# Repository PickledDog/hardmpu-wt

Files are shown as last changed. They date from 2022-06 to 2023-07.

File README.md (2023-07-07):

# hardmpu-wt
 HardMPU with wavetable module support

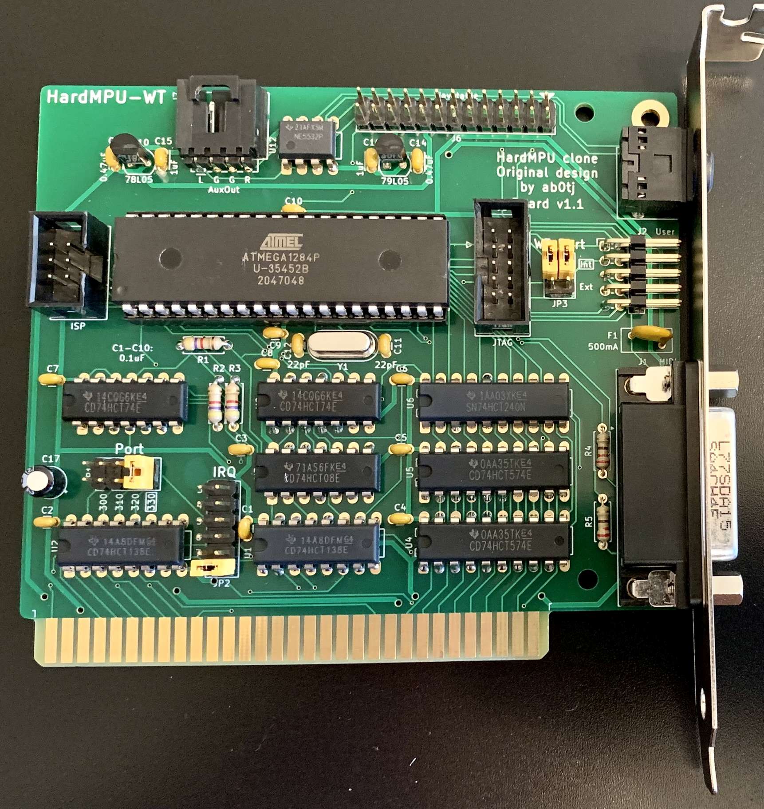
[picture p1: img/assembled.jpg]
Assembled HardMPU


## Overview
This is a clone of ab0tj's HardMPU board. I wanted one with a "Wave Blaster" header, so... here it is! If you don't need to install a wavetable module on your HardMPU, rather use ab0tj's original board. In particular, to quote the HardMPU repo, `the circuit design is free for non-commercial use.` The presence of this implementation does not permit commercial exploitation. If you build this, you may do so only for your own personal use. All [software](https://github.com/ab0tj/HardMPU/) is bound by the terms of the GPL. 

## Initial setup
The ATmega needs to be programmed before use. This can be done using any AVR programmer (AVRISP, STK500, USBtinyISP, USBasp etc), or a universal programmer (TL866, T48).

### Using an AVR programmer
This method programs the ATmega chip in-place (with the board fully assembled), through the J4 ISP connector. The listed programmers work similarly, but AVRDUDE will need to be told what programmer you are using. This example uses the [programmer from Pololu](https://www.pololu.com/product/3172).

Program the board loose (not plugged into a computer!) with the programmer configured to power the target at 5V. The required firmware can be found [in ab0tj's repository](https://github.com/ab0tj/HardMPU/tree/master/bin) (download all files), and [AVRDUDE](https://github.com/avrdudes/avrdude/) is used to install the firmware onto the ATmega.

You will need to modify the `program.bat` to reflect your programmer and environment. For example, to use a Pololu programmer detected at COM4, change (per-line):
```
-c usbasp-clone
```
to
```
-c stk500v2 -P COM4
```
For Mac and Linux, change the BATch file to a shell script and adapt it accordingly (use `/dev/ttyUSB0` instead of `COM4` etc).

### Using a TL866
If you're using a TL866 or T48, the firmware is programmed directly to the ATmega chip before installing it - the J4 connector isn't used here, and can be omitted. Download `HardMPU.hex` from [ab0tj's repository](https://github.com/ab0tj/HardMPU/tree/master/bin) and open it with the standard XGpro tool. Go to the **Config** tab and set the fuses as follows:

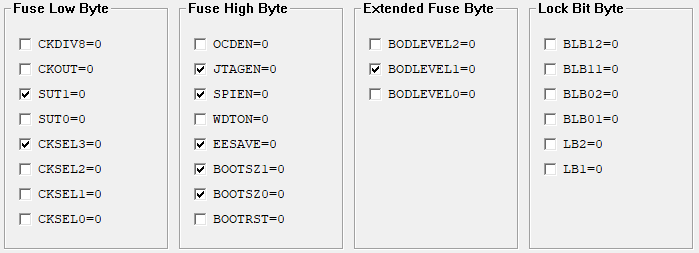
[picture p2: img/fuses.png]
ATmega1284 fuse config


With the firmware loaded and the fuses set, go ahead and program the ATmega chip.

## User port
The optional User port (J2) allows adventurous builders to add features to the board, either internally or externally. It breaks out 4 GPIO pins, an I²C interface, the "Internal" serial interface (shared with the Wavetable header), and fused power and ground pins. Either regular or right-angled header (as pictured) can be installed in the J2 position; a hole will need to be cut in the bracket for external access. You will need to write your own code to use these interfaces - maybe add a status display using a common I²C LCD? The possibilities are not particularly limited!

## Usage
With the card built and the chip programmed, it's ready to be installed in the ISA slot of your vintage PC. Copy `hardmpu.com` from the firmware folder above to the PC's hard drive - this is the config tool for HardMPU. Use it to select between internal and external MIDI devices, enable a delay for "rev 0" Roland MT-32s, and other miscellaneous options. Settings *do not persist* across reboots, so this will need to be added to `autoexec.bat` if the defaults aren't adequate.

### External MIDI
To connect it to an external synthesizer, you'll need a "Sound Blaster MIDI" cable - you can find a used one, [buy a new one](https://www.ebay.com/sch/i.html?_nkw=game+port+midi+cable), or [build your own](https://github.com/PickledDog/sb-midi). If shopping for a new one, *make sure to pick the one with large black DA-15 plugs* since it has the electronics in the plug. ***Do not use the "metal plugs" kind, they are passive and may damage your synthesizer.***

### Internal MIDI ("Wave Blaster")
Plug the wavetable board onto the 26-pin header, aligning the pin 1 arrows on both boards. Audio is output through both the 3.5mm jack and the AuxOut header on the board. The latter can be fed into your regular sound card using a standard "MPC2" CD Audio cable (assuming it has a spare input). You will need to use the `hardmpu.com` tool to select the internal MIDI port.

## Part selection
The design permits "nicer" parts than necessary - for example, the audio jack footprint accepts both switched and unswitched sockets. Not all pads and holes in the board need to be filled. The OPA2134 can be substituted for other common dual opamps (like the NE5532). Some connectors are optional - J2 and J5 in particular are seldom-used. An [ATmega1284](https://www.mouser.com/ProductDetail/556-ATMEGA1284-PU) can be used in place of the ATmega1284P if the latter isn't in stock; you will need to update `program.bat` accordingly.

## Parts list
Bill Of Materials and part references are below. The specified parts are just the ones I used, and can be substituted as needed - Mouser links provided for convenience and reference. You will need to drill a single hole in the specified bracket for the audio jack - refer to the PCB file for size and location.

| Reference | Value | Qty | Mouser link |
| --- | ----- | --- | --- |
| C1-C10 | 0.1uF ceramic | 10 | [KEMET C315C104M5U5TA](https://www.mouser.com/ProductDetail/80-C315C104M5U-TR) |
| C11, C12 | 22pF ceramic | 2 | [KEMET C315C220K2G5TA](https://www.mouser.com/ProductDetail/80-C315C220K2G) |
| C13, C14 | 0.47uF ceramic | 2 | [TDK FG18X7R1H474K](https://www.mouser.com/ProductDetail/810-FG18X7R1H474KRT0) |
| C15, C16 | 1uF ceramic | 2 | [TDK FG18X7R1E105K](https://www.mouser.com/ProductDetail/810-FG18X7R1E105KRT0) |
| C17 | 22μF electrolytic | 1 | [Panasonic ECE-A1AKS220](https://www.mouser.com/ProductDetail/667-ECE-A1AKS220) |
| F1 | 500mA PPTC fuse | 1 | [Bourns MF-R050-0-17](https://www.mouser.com/ProductDetail/652-MF-R050-0-17) |
| J1 | D-Sub DA-15 female | 1 | [Amphenol L77SDA15SA4CH4F](https://www.mouser.com/ProductDetail/523-L77SDA15SA4CH4F) |
| J2 | 2x5 right-angle header | 1 | [Amphenol 10129382-910002BLF](https://www.mouser.com/ProductDetail/649-1012938291002BLF) |
| J3 | 3.5mm jack socket | 1 | [CUI SJ1-3553NG](https://www.mouser.com/ProductDetail/490-SJ1-3553NG) |
| J4 | 2x3 box header | 1 | [Wurth 61200621621](https://www.mouser.com/ProductDetail/710-61200621621) |
| J5 | 2x5 box header | 1 | [Wurth 61201021621](https://www.mouser.com/ProductDetail/710-61201021621) |
| J6 | 2x13 header | 1 | [Amphenol 67997-226HLF](https://www.mouser.com/ProductDetail/649-67997-226HLF) |
| J7 | CD-Audio socket | 1 | [Molex 70551-0003](https://www.mouser.com/ProductDetail/538-70551-0003) |
| JP1 | 2x4 header | 1 | [Amphenol 10129381-908002BLF](https://www.mouser.com/ProductDetail/649-1012938190802BLF) |
| JP2 | 2x6 header | 1 | [Amphenol 10129381-912002BLF](https://www.mouser.com/ProductDetail/649-1012938191202BLF) |
| JP3 | 2x3 header | 1 | [Amphenol 10129381-906002BLF](https://www.mouser.com/ProductDetail/649-1012938190602BLF) |
| | jumpers | 4 | [Harwin M7583-46](https://www.mouser.com/ProductDetail/855-M7583-46)
| R1-R3 | 4k7Ω resistor | 3 | [Yageo CFR-25JR-52-4K7](https://www.mouser.com/ProductDetail/603-CFR-25JR-524K7) |
| R4, R5 | 220Ω resistor | 2 | [Yageo CFR-25JR-52-220R](https://www.mouser.com/ProductDetail/603-CFR-25JR-52220R) |
| U1, U2 | 74HCT138 | 2 | [TI CD74HCT138E](https://www.mouser.com/ProductDetail/595-CD74HCT138E) |
| U3 | 74HCT08 | 1 | [TI CD74HCT08E](https://www.mouser.com/ProductDetail/595-CD74HCT08E) |
| U4, U5 | 74HCT574 | 2 | [TI CD74HCT574E](https://www.mouser.com/ProductDetail/595-CD74HCT574E) |
| U6 | 74HCT240 | 1 | [TI SN74HCT240N](https://www.mouser.com/ProductDetail/595-SN74HCT240N) |
| U7, U8 | 74HCT74 | 2 | [TI CD74HCT74E](https://www.mouser.com/ProductDetail/595-CD74HCT74E) |
| U9 | ATmega1284P | 1 | [Atmel ATmega1284P](https://www.mouser.com/ProductDetail/556-ATMEGA1284P-PU) |
| | socket | 1 | [Amphenol DILB40P-223TLF](https://www.mouser.com/ProductDetail/649-DILB40P223TLF) |
| U10 | 78L05 | 1 | [ST L78L05ACZ](https://www.mouser.com/ProductDetail/511-L78L05ACZ) |
| U11 | 79L05 | 1 | [ST L79L05ACZ](https://www.mouser.com/ProductDetail/511-L79L05ACZ) |
| U12 | OPA2134 | 1 | [TI OPA2134PA](https://www.mouser.com/ProductDetail/595-OPA2134PA) |
| Y1 | 20MHz crystal | 1 | [Arbacon ABL-20.000MHz-B1U](https://www.mouser.com/ProductDetail/815-ABL-20-B1U) |
| bracket | ISA DA-15 bracket | 1 | [Keystone 9200-11](https://www.mouser.com/ProductDetail/534-9200-11) |

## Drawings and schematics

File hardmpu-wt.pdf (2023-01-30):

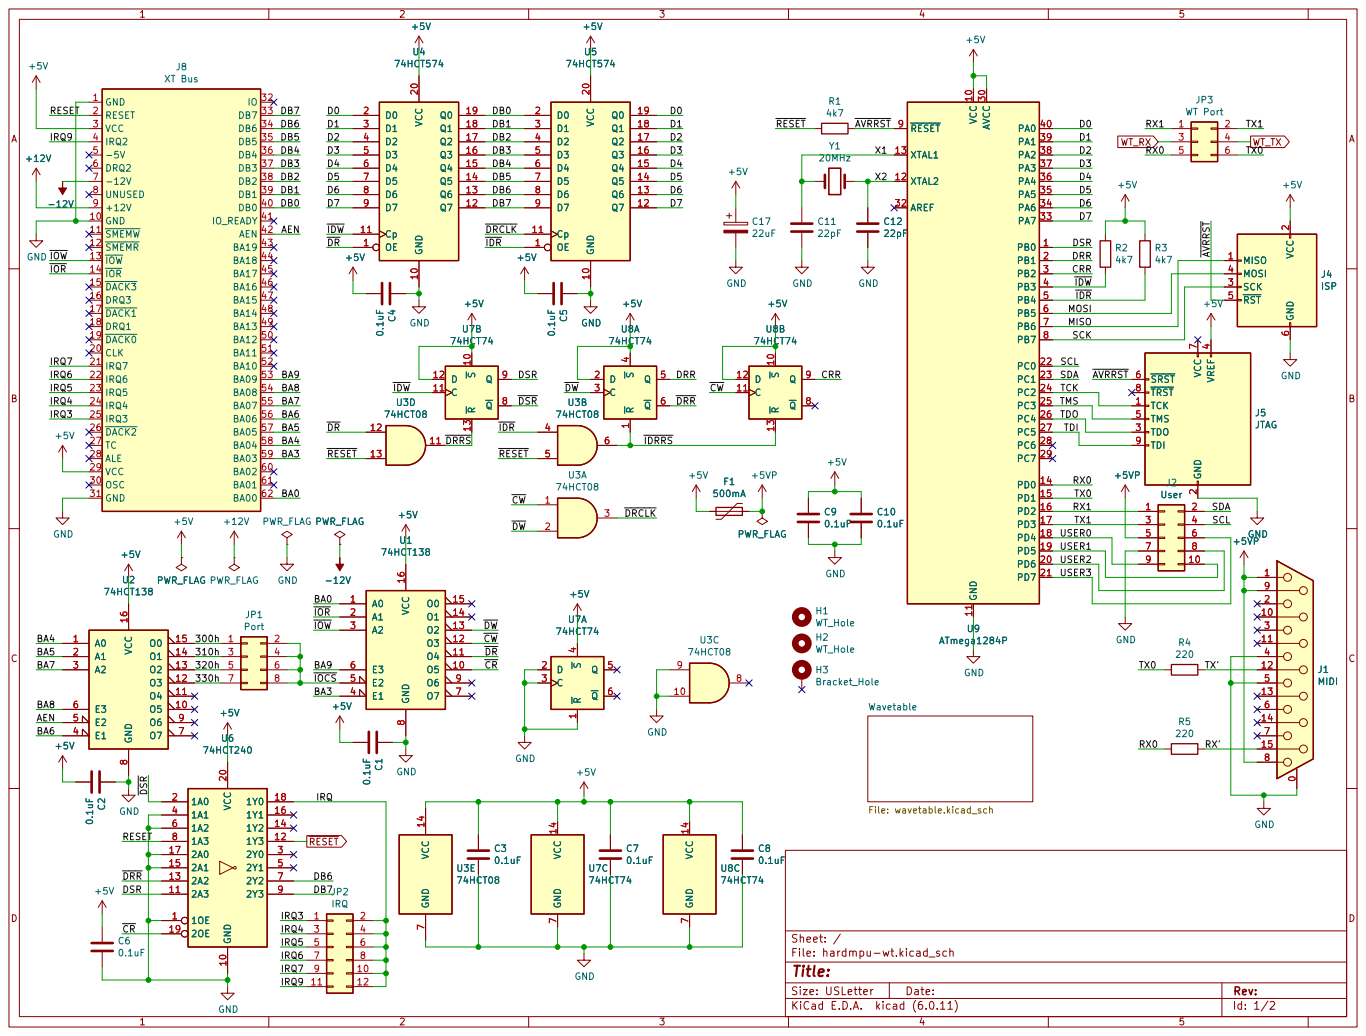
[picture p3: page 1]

2 SCK 3 MOSI 4 ~{RST} 5 GND

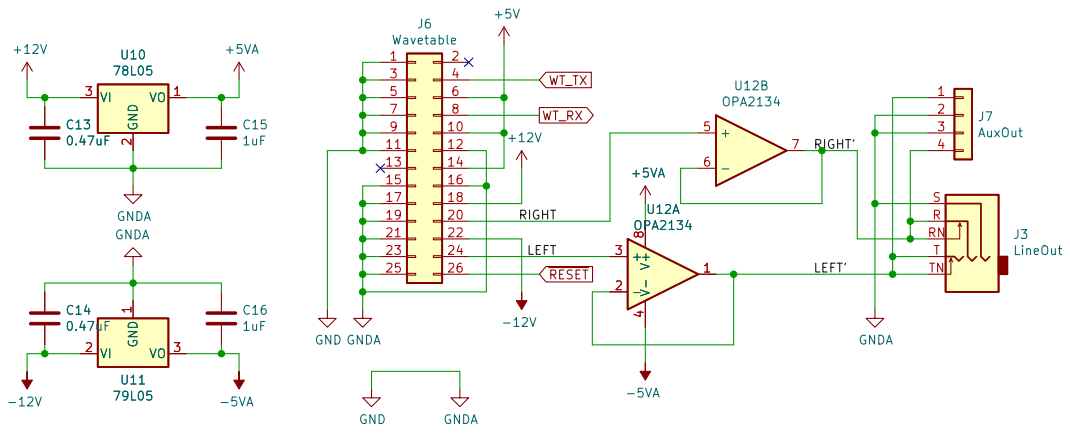
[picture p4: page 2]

17 | 18
19 | 20

Id: 2/2 Title: File: wavetable.kicad_sch Sheet: /Wavetable/

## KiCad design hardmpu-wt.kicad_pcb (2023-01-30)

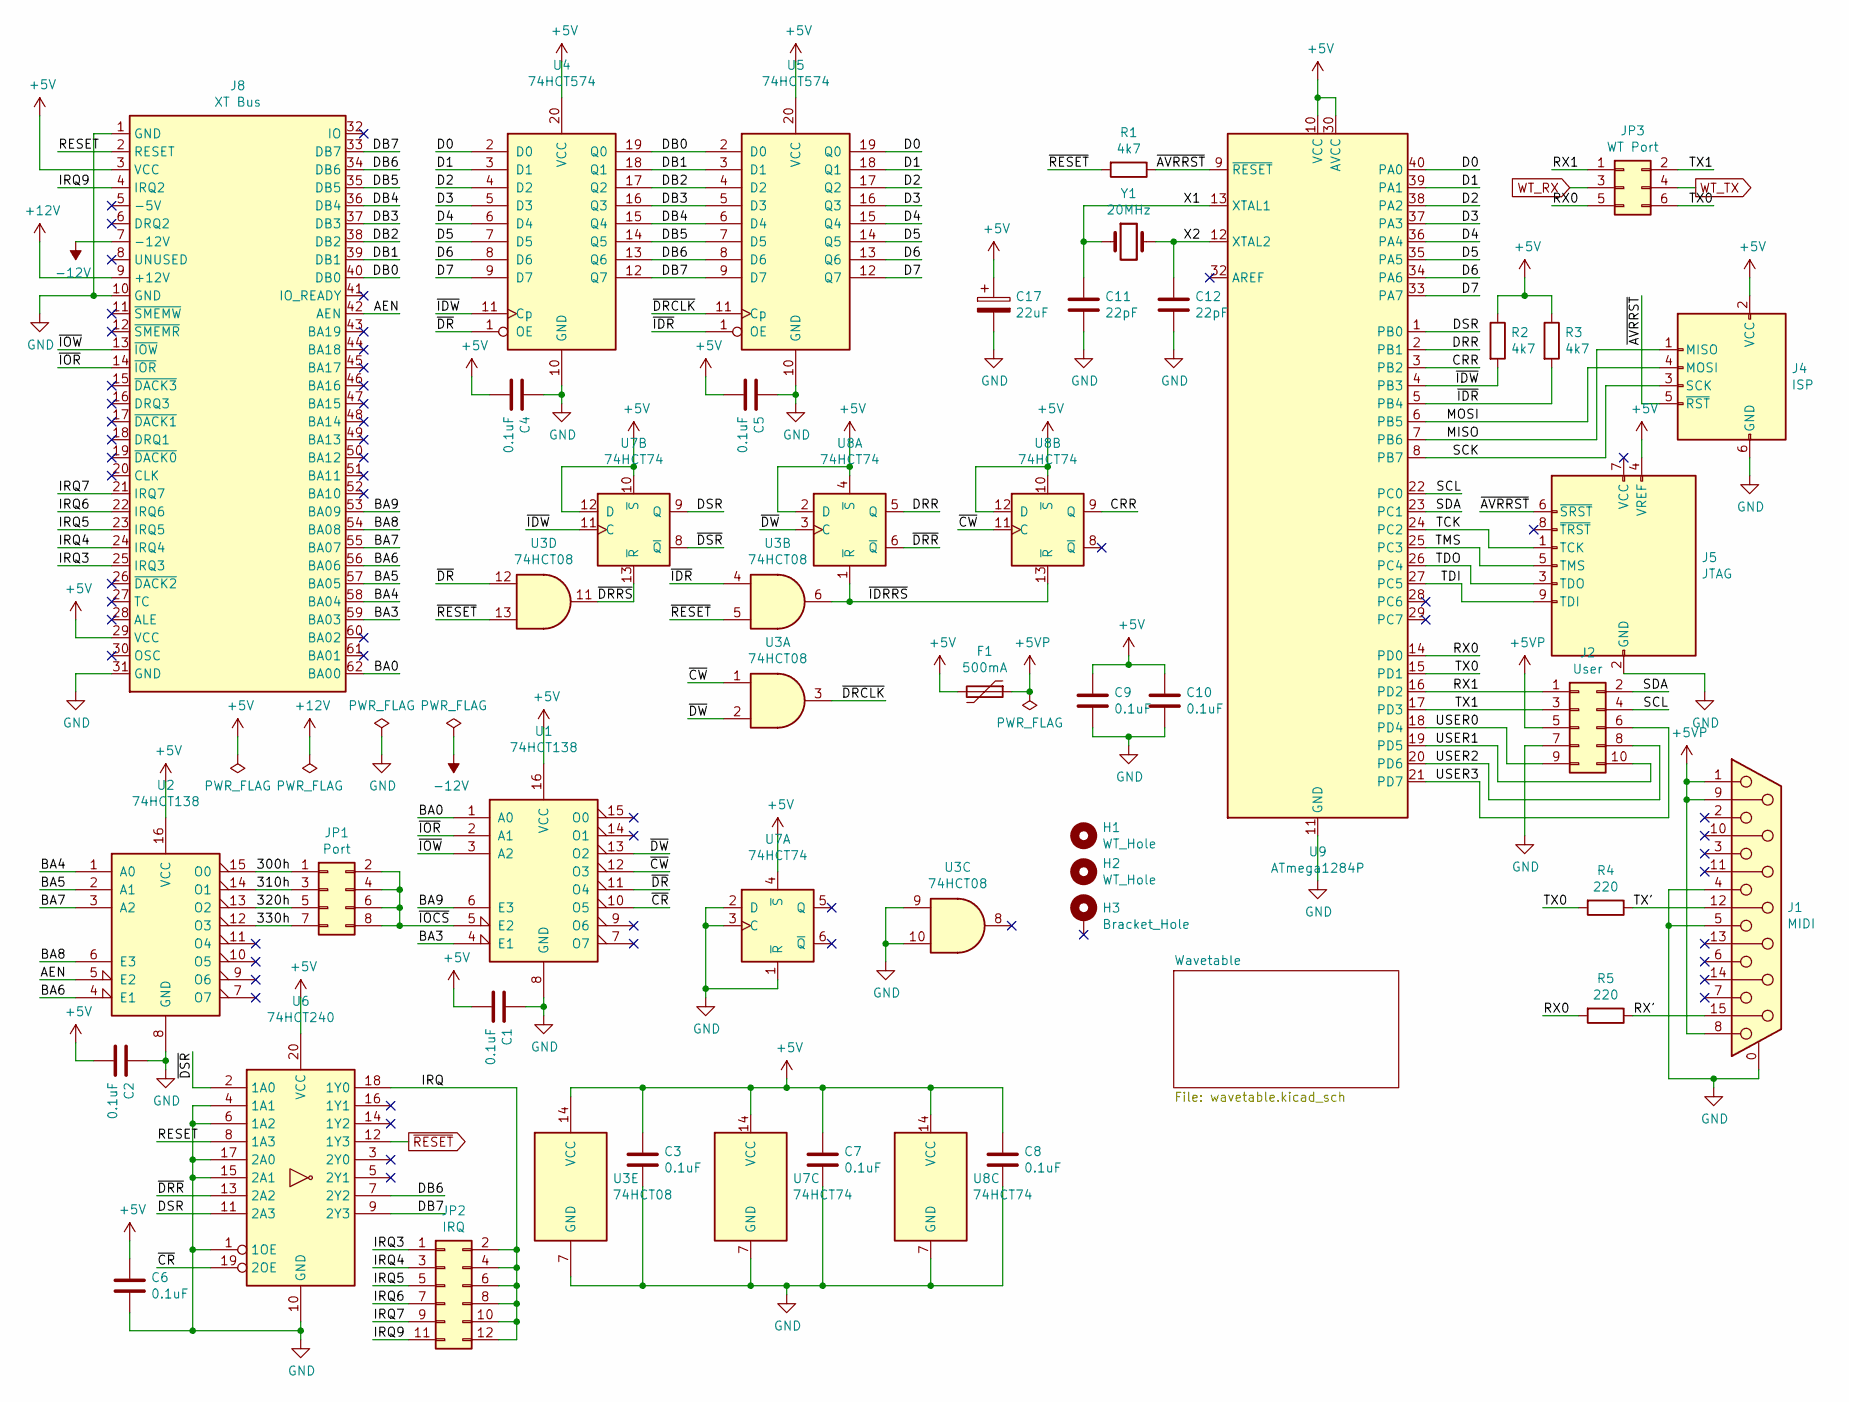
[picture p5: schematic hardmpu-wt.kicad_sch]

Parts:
C1, C2, C3, C4, C5, C6, C7, C8, C9, C10: 0.1uF; C_Disc_D3.0mm_W1.6mm_P2.50mm
C11, C12: 22pF; C_Disc_D3.0mm_W1.6mm_P2.50mm
C17: 22uF; CP_Radial_D5.0mm_P2.00mm
F1: 500mA; Fuse_BelFuse_0ZRE0005FF_L8.3mm_W3.8mm
H1, H2: WT_Hole; MountingHole_3.2mm_M3
H3: Bracket_Hole; MountingHole_3.2mm_M3_Pad
J1: MIDI; DSUB-15_Female_Horizontal_P2.77x2.84mm_EdgePinOffset7.70mm_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
J2: User; PinHeader_2x05_P2.54mm_Horizontal
J4: ISP; IDC-Header_2x03_P2.54mm_Vertical
J5: JTAG; IDC-Header_2x05_P2.54mm_Vertical
J8: XT Bus; BUS_XT
JP1: Port; PinHeader_2x04_P2.54mm_Vertical
JP2: IRQ; PinHeader_2x06_P2.54mm_Vertical
JP3: WT Port; PinHeader_2x03_P2.54mm_Vertical
R1, R2, R3: 4k7; R_Axial_DIN0207_L6.3mm_D2.5mm_P7.62mm_Horizontal
R4, R5: 220; R_Axial_DIN0207_L6.3mm_D2.5mm_P7.62mm_Horizontal
U1, U2: 74HCT138; DIP-16_W7.62mm_LongPads
U3: 74HCT08; DIP-14_W7.62mm_LongPads
U4, U5: 74HCT574; DIP-20_W7.62mm_LongPads
U6: 74HCT240; DIP-20_W7.62mm_LongPads
U7, U8: 74HCT74; DIP-14_W7.62mm_LongPads
U9: ATmega1284P; DIP-40_W15.24mm_LongPads
Y1: 20MHz; Crystal_HC49-4H_Vertical

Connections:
+5V: C1.2, C2.2, C3.1, C4.2, C5.2, C6.1, C7.1, C8.1, C9.1, C10.1, C17.1, F1.2, J4.2 (VCC), J5.4 (VREF), J8.3 (VCC), J8.29 (VCC), R2.1, R3.1, U1.16 (VCC), U2.16 (VCC), U3.14 (VCC), U4.20 (VCC), U5.20 (VCC), U6.20 (VCC), U7.4 (~S), U7.10 (~S), U7.12 (D), U7.14 (VCC), U8.2 (D), U8.4 (~S), U8.10 (~S), U8.12 (D), U8.14 (VCC), U9.10 (VCC), U9.30 (AVCC); also elsewhere on the board
+5VP: F1.1, J1.1, J1.8, J1.9, J2.5
+12V: J8.9 (+12V); also elsewhere on the board
-12V: J8.7 (-12V); also elsewhere on the board
/300h: JP1.1, U2.15 (O0)
/310h: JP1.3, U2.14 (O1)
/320h: JP1.5, U2.13 (O2)
/330h: JP1.7, U2.12 (O3)
/AEN: J8.42 (AEN), U2.5 (E2)
/BA0: J8.62 (BA00), U1.1 (A0)
/BA3: J8.59 (BA03), U1.4 (E1)
/BA4: J8.58 (BA04), U2.1 (A0)
/BA5: J8.57 (BA05), U2.2 (A1)
/BA6: J8.56 (BA06), U2.4 (E1)
/BA7: J8.55 (BA07), U2.3 (A2)
/BA8: J8.54 (BA08), U2.6 (E3)
/BA9: J8.53 (BA09), U1.6 (E3)
/CRR: U8.9 (Q), U9.3 (PB2)
/D0: U4.2 (D0), U5.19 (Q0), U9.40 (PA0)
/D1: U4.3 (D1), U5.18 (Q1), U9.39 (PA1)
/D2: U4.4 (D2), U5.17 (Q2), U9.38 (PA2)
/D3: U4.5 (D3), U5.16 (Q3), U9.37 (PA3)
/D4: U4.6 (D4), U5.15 (Q4), U9.36 (PA4)
/D5: U4.7 (D5), U5.14 (Q5), U9.35 (PA5)
/D6: U4.8 (D6), U5.13 (Q6), U9.34 (PA6)
/D7: U4.9 (D7), U5.12 (Q7), U9.33 (PA7)
/DB0: J8.40 (DB0), U4.19 (Q0), U5.2 (D0)
/DB1: J8.39 (DB1), U4.18 (Q1), U5.3 (D1)
/DB2: J8.38 (DB2), U4.17 (Q2), U5.4 (D2)
/DB3: J8.37 (DB3), U4.16 (Q3), U5.5 (D3)
/DB4: J8.36 (DB4), U4.15 (Q4), U5.6 (D4)
/DB5: J8.35 (DB5), U4.14 (Q5), U5.7 (D5)
/DB6: J8.34 (DB6), U4.13 (Q6), U5.8 (D6), U6.7 (2Y2)
/DB7: J8.33 (DB7), U4.12 (Q7), U5.9 (D7), U6.9 (2Y3)
/DRR: U8.5 (Q), U9.2 (PB1)
/DSR: U6.11 (2A3), U7.9 (Q), U9.1 (PB0)
/IRQ: JP2.2, JP2.4, JP2.6, JP2.8, JP2.10, JP2.12, U6.18 (1Y0)
/IRQ3: J8.25 (IRQ3), JP2.1
/IRQ4: J8.24 (IRQ4), JP2.3
/IRQ5: J8.23 (IRQ5), JP2.5
/IRQ6: J8.22 (IRQ6), JP2.7
/IRQ7: J8.21 (IRQ7), JP2.9
/IRQ9: J8.4 (IRQ2), JP2.11
/MISO: J4.1 (MISO), U9.7 (PB6)
/MOSI: J4.4 (MOSI), U9.6 (PB5)
/RESET: J8.2 (RESET), U6.8 (1A3)
/RX0: JP3.5, R5.2, U9.14 (PD0)
/RX1: J2.1, JP3.1, U9.16 (PD2)
/RX': J1.15, R5.1
/SCK: J4.3 (SCK), U9.8 (PB7)
/SCL: J2.4, U9.22 (PC0)
/SDA: J2.2, U9.23 (PC1)
/TCK: J5.1 (TCK), U9.24 (PC2)
/TDI: J5.9 (TDI), U9.27 (PC5)
/TDO: J5.3 (TDO), U9.26 (PC4)
/TMS: J5.5 (TMS), U9.25 (PC3)
/TX0: JP3.6, R4.2, U9.15 (PD1)
/TX1: J2.3, JP3.2, U9.17 (PD3)
/TX': J1.12, R4.1
/USER0: J2.9, U9.18 (PD4)
/USER1: J2.10, U9.19 (PD5)
/USER2: J2.8, U9.20 (PD6)
/USER3: J2.6, U9.21 (PD7)
/X1: C11.1, U9.13 (XTAL1), Y1.1
/X2: C12.1, U9.12 (XTAL2), Y1.2
/~AVRRST: J4.5 (~RST), J5.6 (~SRST), R1.1, U9.9 (~RESET)
/~CR: U1.10 (O5), U6.19 (2OE)
/~CW: U1.12 (O3), U3.1, U8.11 (C)
/~DRCLK: U3.3, U5.11 (Cp)
/~DRRS: U3.11, U7.13 (~R)
/~DRR: U6.13 (2A2), U8.6 (~Q)
/~DR: U1.11 (O4), U3.12, U4.1 (OE)
/~DSR: U6.2 (1A0), U7.8 (~Q)
/~DW: U1.13 (O2), U3.2, U8.3 (C)
/~IDRRS: U3.6, U8.1 (~R), U8.13 (~R)
/~IDR: R3.2, U3.4, U5.1 (OE), U9.5 (PB4)
/~IDW: R2.2, U4.11 (Cp), U7.11 (C), U9.4 (PB3)
/~IOCS: JP1.2, JP1.4, JP1.6, JP1.8, U1.5 (E2)
/~IOR: J8.14 (~IOR), U1.2 (A1)
/~IOW: J8.13 (~IOW), U1.3 (A2)
GND: C1.1, C2.1, C3.2, C4.1, C5.1, C6.2, C7.2, C8.2, C9.2, C10.2, C11.2, C12.2, C17.2, J1.0 (PAD), J1.4, J1.5, J2.7, J4.6 (GND), J5.2 (GND), J5.10 (GND), J8.1 (GND), J8.10 (GND), J8.31 (GND), U1.8 (GND), U2.8 (GND), U3.7 (GND), U3.9, U3.10, U4.10 (GND), U5.10 (GND), U6.1 (1OE), U6.4 (1A1), U6.6 (1A2), U6.10 (GND), U6.15 (2A1), U6.17 (2A0), U7.1 (~R), U7.2 (D), U7.3 (C), U7.7 (GND), U8.7 (GND), U9.11 (GND), U9.31 (GND); also elsewhere on the board
WT_RX: JP3.3; also elsewhere on the board
WT_TX: JP3.4; also elsewhere on the board
~RESET: R1.2, U3.5, U3.13, U6.12 (1Y3); also elsewhere on the board

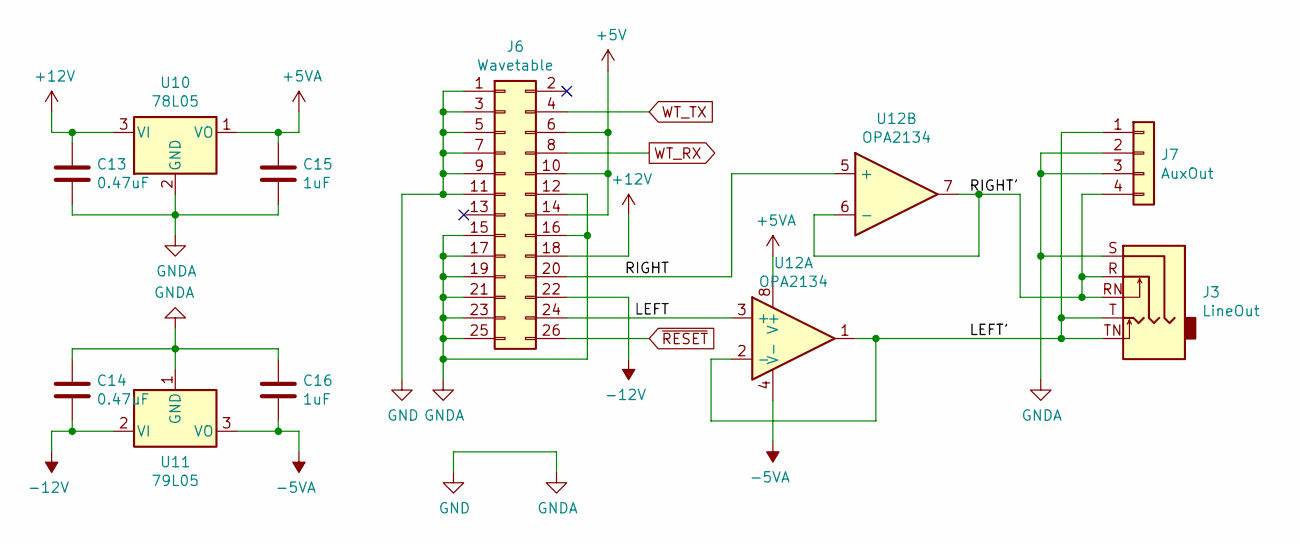
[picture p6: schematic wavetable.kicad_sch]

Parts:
C13, C14: 0.47uF; C_Disc_D3.0mm_W2.0mm_P2.50mm
C15, C16: 1uF; C_Disc_D3.0mm_W2.0mm_P2.50mm
J3: LineOut; Jack_3.5mm_CUI_SJ1-3555NG
J6: Wavetable; PinHeader_2x13_P2.54mm_Vertical
J7: AuxOut; Molex_SL_70551-0003_1x04_P2.54mm_Horizontal
U10: 78L05; TO-92
U11: 79L05; TO-92
U12: OPA2134; DIP-8_W7.62mm_LongPads

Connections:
+5V: J6.6, J6.10, J6.14; also elsewhere on the board
+5VA: C15.1, U10.1 (VO), U12.8 (V+)
+12V: C13.1, J6.18, U10.3 (VI); also elsewhere on the board
-5VA: C16.2, U11.3 (VO), U12.4 (V-)
-12V: C14.2, J6.22, U11.2 (VI); also elsewhere on the board
/Wavetable/LEFT: J6.24, U12.3 (+)
/Wavetable/LEFT': J3.T, J3.TN, J7.1, U12.1, U12.2 (-)
/Wavetable/RIGHT: J6.20, U12.5 (+)
/Wavetable/RIGHT': J3.R, J3.RN, J7.4, U12.6 (-), U12.7
GND: C13.2, C14.1, C15.2, C16.1, J3.S, J6.1, J6.3, J6.5, J6.7, J6.9, J6.11, J6.12, J6.15, J6.16, J6.17, J6.19, J6.21, J6.23, J6.25, J7.2, J7.3, U10.2 (GND), U11.1 (GND); also elsewhere on the board
WT_RX: J6.8; also elsewhere on the board
WT_TX: J6.4; also elsewhere on the board
~RESET: J6.26; also elsewhere on the board

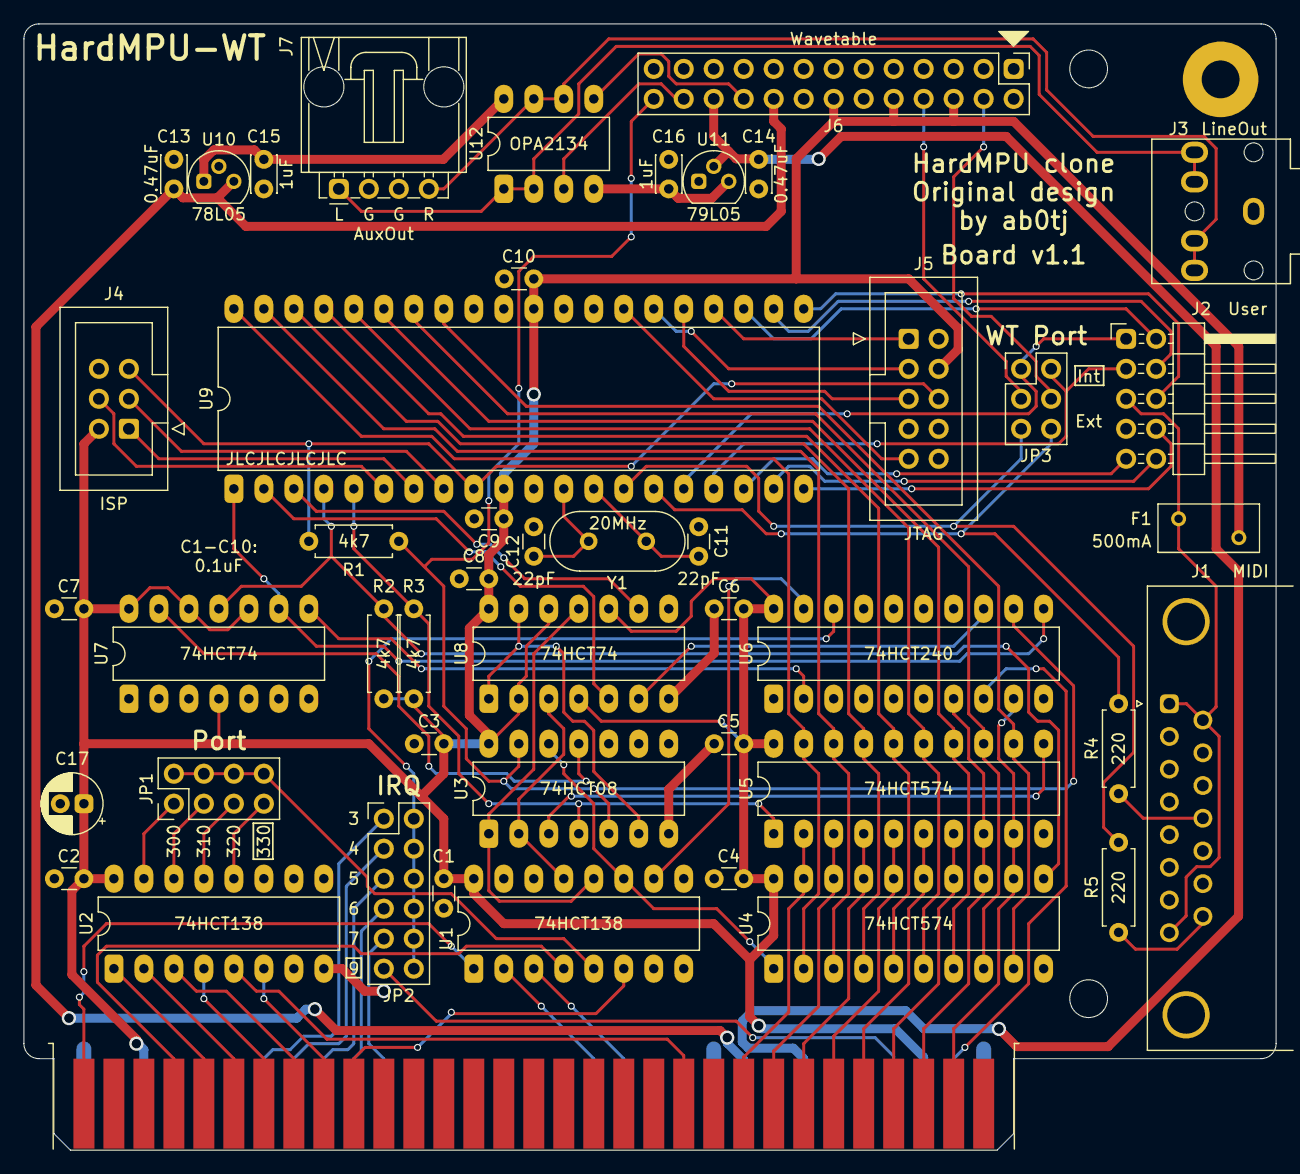
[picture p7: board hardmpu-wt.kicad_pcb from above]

Board: 2 copper layers, 106.0 x 95.4 mm, 50 parts (0 on the bottom side), 90 nets.

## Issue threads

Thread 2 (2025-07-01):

Possible Unauthorized Commercial Use of HardMPU

parabellum-push, 2025-07-01:
I wanted to bring to your attention that I recently came across a listing for a commercial product that appears to be based on your HardMPU project. The seller is offering it for sale and claims to have "commissioned you" for the PCB design. Given that HardMPU is licensed for free non-commercial use, I thought it might be important to verify whether this usage is authorized.

Of course, it's entirely possible that there is a legitimate arrangement in place, but I felt it was respectful to inform you just in case this claim was made without your knowledge or consent.

The listing in question : https://cafe.naver.com/cjcj/82124

ab0tj, 2025-07-01:
I'm just going to reply here to keep the discussion in one place, as this issue was also opened on the repo for my original design. My original intent was just to prevent people from mass producing these things and claiming it as their own, but if I understand correctly the person in question here is just selling a few extra boards that they assembled?

parabellum-push, 2025-07-01:
Thank for your reply! Sorry for the duplicate github issue.
It is implied that he assembled and sold more than what is shown on the photos. In regard of your design and its modified versions, I assume it is ok to build and sell a few boards at a time as long as you are credited for the design?

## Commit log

2022-04-16 Tweak component values
    [hardmpu-wt-B_Cu.gbr, hardmpu-wt-B_Mask.gbr, hardmpu-wt-B_SilkS.gbr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]
2022-05-03 Add photo of board
2022-05-20 Move DA-15 so board aligns with Keystone 9200-11 bracket
    Adapt board to fit common Keystone 9200-11, add jumpers to switch wavetable between Internal and External UART
    [hardmpu-wt-B_Cu.gbr, hardmpu-wt-B_Mask.gbr, hardmpu-wt-B_SilkS.gbr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]
2022-05-20 Update README to reflect board version 1.1
2022-06-20 Update photo for board v1.1, flesh out README
2023-01-30 Migrate project to KiCad 6
    [hardmpu-wt-B_Cu.gbr, hardmpu-wt-B_Mask.gbr, hardmpu-wt-B_SilkS.gbr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]
